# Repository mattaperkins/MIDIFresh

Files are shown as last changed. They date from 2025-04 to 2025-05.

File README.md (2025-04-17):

<h1>MIDIFresh </h1>

<p>Is a pocket DJ mixing console using MIDI over Bluetooth low energy. I use it with Traktor Pro 4 but it should work with almost any DJ software that allows MIDI Mappings for a controller. 
</p>
<p>
The project uses an Adafruit ESP32-S3 Reverse TFT Feather Microcontroller at the heart and then some simple 10k potentiometers for cross fader and knobs. The microcontroller board has some buttons built in which are also utilized. 
</p>

<p>
There are included .stl files to print the case my design is simple and a bit steam punk with the microcontroller on the external side.  Likely a nicer case could be produced. 
</p>

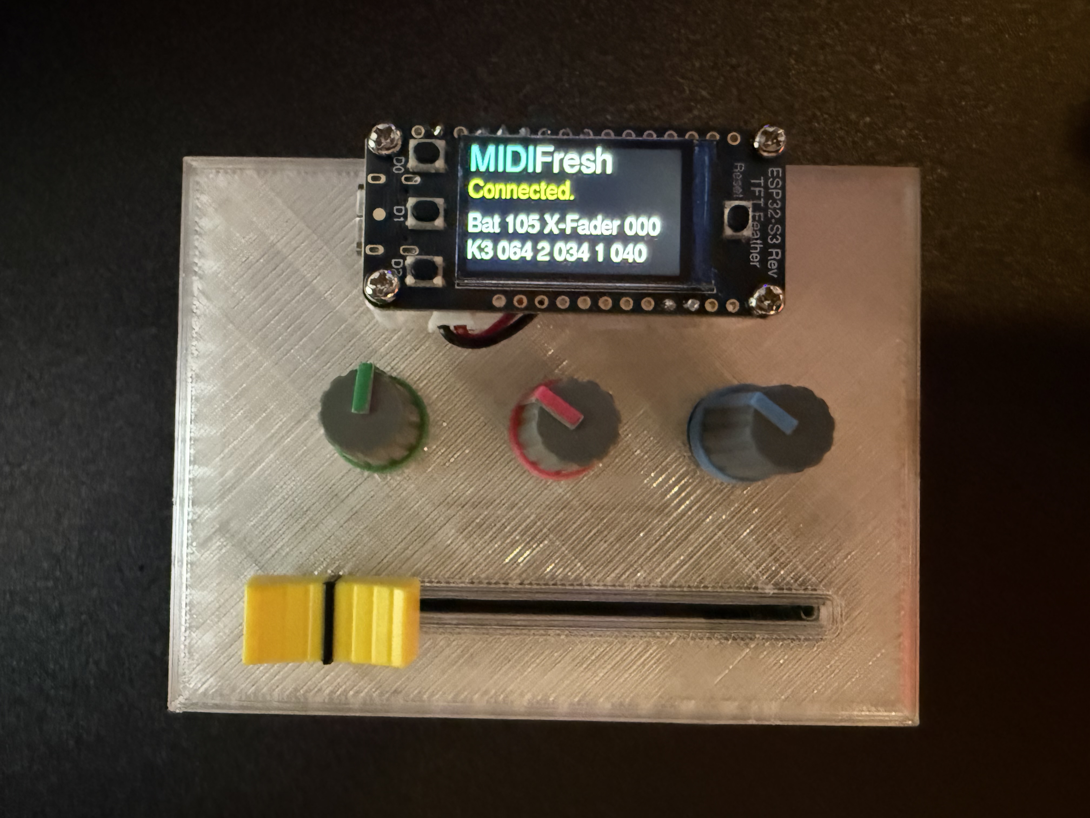
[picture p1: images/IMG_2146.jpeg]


<h3>Parts List. </h3>
<pre>
3 X 10k rotary potentiometer. (linear) 
1 X 10k slider/fader type potentiometer (linear) 
Adafruit ESP32-S3 Reverse TFT Feather – 4MB 
3 plastic knobs
1 plastic fader knob. 
3.2v LIPO that will fit in the case. 
</pre>

<h3>Construction</h3>

<p>The case can be printed in 3 parts and superglued together. I glued in the fader, The knobs and fader should all be connected to analogue pins on the microcontroller with +3v and 0v connected to each side and the LIPO connected to the DC/Bat port. 
</p>

<p>
There are some simple adjustments that can be done in the code that allows the use of different pins. Should be self-explanatory. 

</p>

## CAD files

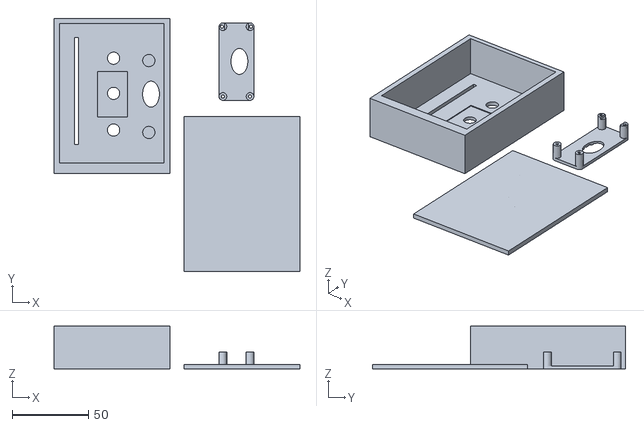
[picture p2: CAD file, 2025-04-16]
3D Models/whole-model.stl
161.0 x 165.6 x 28.0

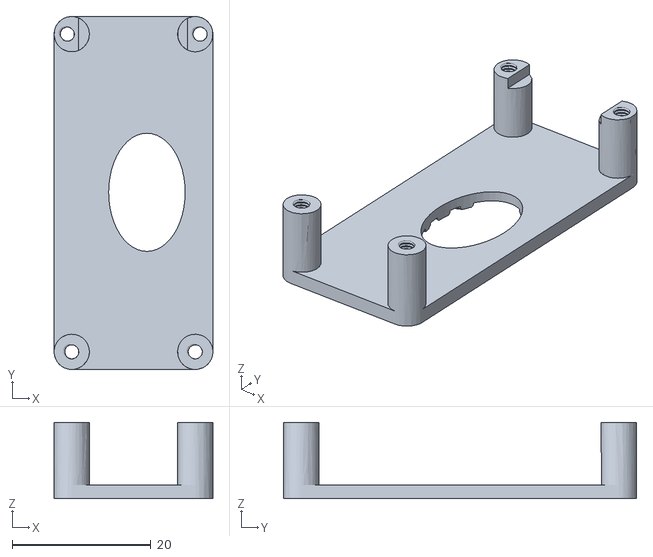
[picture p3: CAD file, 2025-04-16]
3D Models/pcb-mount.stl
22.9 x 50.8 x 11.0

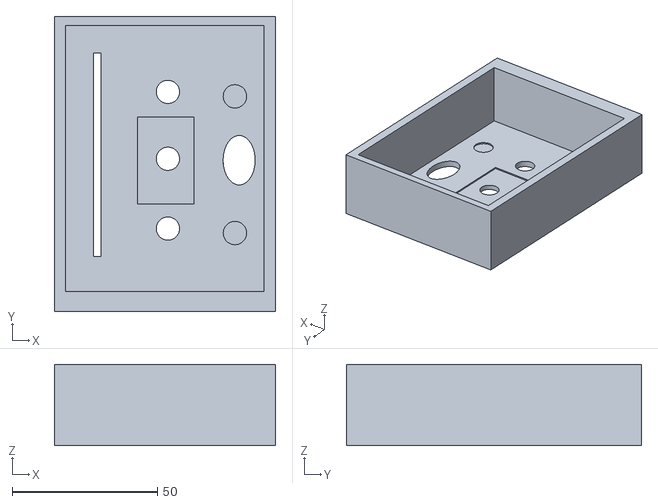
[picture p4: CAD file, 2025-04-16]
3D Models/console.stl
76.0 x 101.6 x 28.0

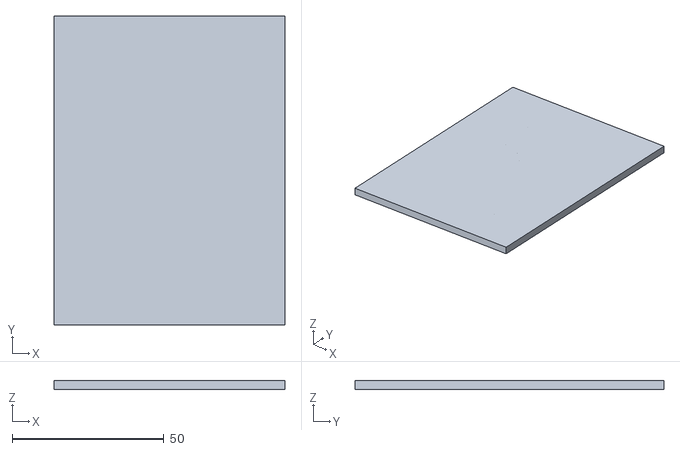
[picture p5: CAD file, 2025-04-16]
3D Models/base.stl
76.0 x 101.6 x 3.00

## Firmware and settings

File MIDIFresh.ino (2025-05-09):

// MIDIFresh
// Matt Perkins - Copyright (C) 2025
// A Tiny MIDI compatable DJ deck for use with Traktor (should work with others)
// Has a cross fader and 3 knobs - Uses a Adafruit Feather ESP32-S3 reverse


/*

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
*/




#include <Arduino.h>
#include <BLEMidi.h>          // BLE Midi Library
#include <Adafruit_GFX.h>     // Core graphics library
#include <Adafruit_ST7789.h>  // Hardware-specific library for ST7789
#include <SPI.h>
#include <Wire.h>               // One Wire lib
#include "Adafruit_MAX1704X.h"  // Battery meter lib.
#include <LiteLED.h>            // LiteLED ES2812 Library for Glowbit 4x4 matrix


// Init Screen
Adafruit_ST7789 tft = Adafruit_ST7789(TFT_CS, TFT_DC, TFT_RST);

// Init Battery Monitor
Adafruit_MAX17048 maxlipo;
bool addr0x36 = true;


// Misc Fonts
#include "Fonts/FreeSans9pt7b.h"
#include "Fonts/FreeSans12pt7b.h"
#include "Fonts/FreeSans18pt7b.h"
#include "Fonts/FreeMono12pt7b.h"

char *mainver = "0.20";  // version

// Midi Channel
const uint8_t midi_channel = 0;

// Crossfader
int crossfader_pin = A3;    // crossfader anaglog pin
int crossfader_min = 3;     // Minimum value for crossfader
int crossfader_max = 4095;  // maximum value for crossfader
int crossfader_midi = 10;   // MIDI Control # for crossfader

// Knob1
int knob1_pin = A0;    // knob1 anaglog pin
int knob1_min = 1;     // Minimum value for knob1
int knob1_max = 4095;  // maximum value for knob1
int knob1_midi = 11;   // MIDI Control # for knob1

// Knob2
int knob2_pin = A1;    // knob2 anaglog pin
int knob2_min = 3;     // Minimum value for knob2
int knob2_max = 4095;  // maximum value for knob2
int knob2_midi = 12;   // MIDI Control # for knob2

// Knob3
int knob3_pin = A2;    // knob3 anaglog pin
int knob3_min = 3;     // Minimum value for knob3
int knob3_max = 4095;  // maximum value for knob3
int knob3_midi = 13;   // MIDI Control # for knob3

//The default buttons
const int buttonPinD0 = 0;  // Replace D1 with the actual pin number
const int buttonPinD1 = 1;  // Replace D1 with the actual pin number
const int buttonPinD2 = 2;  // Replace D2 with the actual pin number



int sleep_timeout = 360;  // Bluetooth timeout before unit goes to sleep to save battery unit X 500ms  = 3 Minutes
int jitter_delay = 50;    // A delay after sending midi to stop some jitter.

// Globit Init
#define LED_TYPE LED_STRIP_WS2812

#define LED_TYPE_IS_RGBW 0  // if the LED matrix uses RGBW type LED's, change the 0 to 1

#define LED_GPIO 5  // change this number to be the GPIO pin connected to DIN of the matrix panel
#define MTRIX_X_SIZE 4
#define MTRIX_LEDS (MTRIX_X_SIZE * MTRIX_X_SIZE)  // total number of LED's in the matrix panel
#define A_DELAY 75                                // # of ms delay between animations within a test
#define TST_PAUSE 1000                            // # of ms to pause between tests
#define REPEAT_DELAY 3000                         // # of ms to delay before repeating all tests

static const uint8_t currBright = 255;  // change this to set the brightness level of the matrix
size_t c = 0;                           // picker for the colour of the LEDs for the currrent test
static const crgb_t L_BLACK = 0x000000;
static const crgb_t colors[] = {
  0x2f0000, /* red */
  0x002f00, /* green */
  0x00002f, /* blue */
  0x0f0f0f  /* white */
};
#define COLORS_TOTAL (sizeof(colors) / sizeof(crgb_t))
LiteLED myDisplay(LED_TYPE, LED_TYPE_IS_RGBW);  // create the LiteLED object




// globals
int old_cross_fader = 0;
int old_knob1 = 0;
int old_knob2 = 0;
int old_knob3 = 0;
int tft_update = 0;
int dyn_update = 0;
int batt = 0;
GFXcanvas1 canvas(230, 67);  // 230x67 pixel canvas for screen update


void setup() {
  // Glowbit INIT
  myDisplay.begin(LED_GPIO, MTRIX_LEDS);  // initialze the myDisplay object.
  myDisplay.brightness(currBright);
  myDisplay.fill(0x00002f, 2);

  // Setup Bluetooth.
  BLEMidiServer.begin("MIDIFresh");
  // Setup Battery monitor
  maxlipo.begin();
  addr0x36 = true;

  // turn on backlite
  pinMode(TFT_BACKLITE, OUTPUT);
  digitalWrite(TFT_BACKLITE, HIGH);

  // Setup display
  pinMode(TFT_I2C_POWER, OUTPUT);
  digitalWrite(TFT_I2C_POWER, HIGH);
  delay(10);

  // initialize TFT
  tft.init(135, 240);  // Init ST7789 240x135
  tft.setRotation(3);

  // Button Setup.
  pinMode(buttonPinD0, INPUT_PULLUP);    // Use INPUT_PULLDOWN for D0
  pinMode(buttonPinD1, INPUT_PULLDOWN);  // Use INPUT_PULLDOWN for D1
  pinMode(buttonPinD2, INPUT_PULLDOWN);  // Use INPUT_PULLDOWN for D2

  tft.fillScreen(ST77XX_BLACK);
  tft.setCursor(0, 20);
  tft.setTextColor(ST77XX_CYAN);
  tft.setTextWrap(true);
  tft.setFont(&FreeSans18pt7b);
  tft.printf("MIDI");
  tft.setTextColor(ST77XX_WHITE);
  tft.print("Fresh");
  tft.setFont(&FreeSans12pt7b);
  tft.setTextColor(ST77XX_YELLOW);
  tft.printf("\nVersion %s\nBy Matt Perkins\nCopyright 2025\n", mainver);
  delay(2000);
}

void loop() {


  if (BLEMidiServer.isConnected()) {
    if (tft_update == 1) {
      tft.fillScreen(ST77XX_BLACK);
      tft.setCursor(0, 25);
      tft.setTextColor(ST77XX_CYAN);
      tft.setTextWrap(true);
      tft.setFont(&FreeSans18pt7b);
      tft.printf("MIDI");
      tft.setTextColor(ST77XX_WHITE);
      tft.print("Fresh");
      tft.setFont(&FreeSans12pt7b);
      tft.setTextColor(ST77XX_YELLOW);
      tft.printf("\nConnected.\n");
      tft_update = 0;
    }
    // Button D0
    int buttonStateD0 = digitalRead(buttonPinD0);
    if (buttonStateD0 == LOW) {
      BLEMidiServer.noteOn(midi_channel, 69, 127);
      delay(300);
      BLEMidiServer.noteOff(midi_channel, 69, 127);
    }

    // Button D1
    int buttonStateD1 = digitalRead(buttonPinD1);
    if (buttonStateD1 == HIGH) {
      BLEMidiServer.noteOn(midi_channel, 71, 127);
      delay(300);
      BLEMidiServer.noteOff(midi_channel, 71, 127);
    }

    // Button D2
    int buttonStateD2 = digitalRead(buttonPinD2);
    if (buttonStateD2 == HIGH) {
      BLEMidiServer.noteOn(midi_channel, 72, 127);
      delay(300);
      BLEMidiServer.noteOff(midi_channel, 72, 127);
    }

    // Crossfader
    int cross_fader = map(analogRead(crossfader_pin), crossfader_min, crossfader_max, 0, 127);
    if (cross_fader != old_cross_fader) {
      old_cross_fader = cross_fader;
      BLEMidiServer.controlChange(midi_channel, crossfader_midi, cross_fader);

      int brightness;

      if (cross_fader <= 64) {
        // Left side: 1 → 255, 64 → 0
        brightness = map(constrain(cross_fader, 1, 64), 1, 64, 255, 0);
        myDisplay.fill(0x2f0000, 1);
      } else {
        // Right side: 65 → 0, 127 → 255
        brightness = map(constrain(cross_fader, 65, 127), 65, 127, 0, 255);
        myDisplay.fill(0x002f00, 1);
      }

      myDisplay.brightness(brightness);




      delay(jitter_delay);
    }

    // Knob 1
    int knob1 = map(analogRead(knob1_pin), knob1_min, knob1_max, 0, 127);
    if (knob1 != old_knob1) {
      old_knob1 = knob1;
      BLEMidiServer.controlChange(midi_channel, knob1_midi, knob1);
      delay(jitter_delay);
    }

    // Knob 2
    int knob2 = map(analogRead(knob2_pin), knob2_min, knob2_max, 0, 127);
    if (knob2 != old_knob2) {
      old_knob2 = knob2;
      BLEMidiServer.controlChange(midi_channel, knob2_midi, knob2);
      delay(jitter_delay);
    }

    // Knob 3
    int knob3 = map(analogRead(knob3_pin), knob3_min, knob3_max, 0, 127);
    if (knob3 != old_knob3) {
      old_knob3 = knob3;
      BLEMidiServer.controlChange(midi_channel, knob3_midi, knob3);
      delay(jitter_delay);
    }

    if (dyn_update == 0) {
      // Update the display with some usefull info
      batt = maxlipo.cellPercent();
      canvas.fillScreen(ST77XX_BLACK);
      canvas.setCursor(0, 24);
      canvas.setFont(&FreeSans12pt7b);
      canvas.printf("Bat %03d X-Fader %03d\nK3 %03d 2 %03d 1 %03d", batt, cross_fader, knob3, knob2, knob1);
      tft.drawBitmap(00, 67, canvas.getBuffer(), 230, 67, ST77XX_WHITE, ST77XX_BLACK);
      dyn_update = 1000;  // Update the display every 20,000 cycles to not slowdown midi
    }

    dyn_update = dyn_update - 1;

  } else {
    // Check if we need to go to powersave
    sleep_timeout = sleep_timeout - 1;
    if (sleep_timeout == 0) {
      myDisplay.brightness(0, 1);
      myDisplay.clear(1);
      maxlipo.hibernate();
      esp_deep_sleep_start();  // Put ESP32 into deep sleep mode to save batter
    }

    if (tft_update == 0) {
      // Display waiting to connect bluetooth.
      tft.fillScreen(ST77XX_BLACK);
      tft.setCursor(0, 25);
      tft.setTextColor(ST77XX_CYAN);
      tft.setTextWrap(true);
      tft.setFont(&FreeSans18pt7b);
      tft.printf("MIDI");
      tft.setTextColor(ST77XX_WHITE);
      tft.print("Fresh");
      tft.setFont(&FreeSans12pt7b);
      tft.setTextColor(ST77XX_YELLOW);
      tft.printf("\nWaiting for Bluetooth.\n");
      tft.setTextColor(ST77XX_RED);
      tft.printf("Will sleep if not found.");
      tft.setTextColor(ST77XX_WHITE);
      batt = maxlipo.cellPercent();
      tft.printf("Bat %03d", batt);
      tft_update = 1;
    }
    delay(500);
  }
}

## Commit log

2025-03-28 Refine code and add 3 buttons total.
2025-04-16 Add 3D Models for the console in STL
    [base.stl, console.stl, pcb-mount.stl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]
2025-04-16 Added battery display and sleep system
2025-04-17 fixed up screen display and general tidy up
    [MIDIFresh.ino]
2025-04-17 added button support as well
2025-05-01 added glowbit LED functionality
2025-05-09 improve battery life when in power save mode

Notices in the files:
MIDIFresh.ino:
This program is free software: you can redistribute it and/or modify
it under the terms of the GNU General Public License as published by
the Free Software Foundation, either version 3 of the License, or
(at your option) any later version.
